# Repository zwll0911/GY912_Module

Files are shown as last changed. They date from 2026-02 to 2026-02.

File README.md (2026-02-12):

# 🚁 Industrial AHRS Navigation Module (V5.5)






> **High-Precision Navigation Core for Competition Robotics**

The **Industrial AHRS Navigation Module** is a robust sensor fusion engine built on the **ESP32-S3**. It delivers stable 6-axis orientation (Yaw, Pitch, Roll) via **1 Mbps CAN Bus** and offers **Dual-Mode Telemetry** (USB Serial + Wireless UDP) for real-time monitoring.

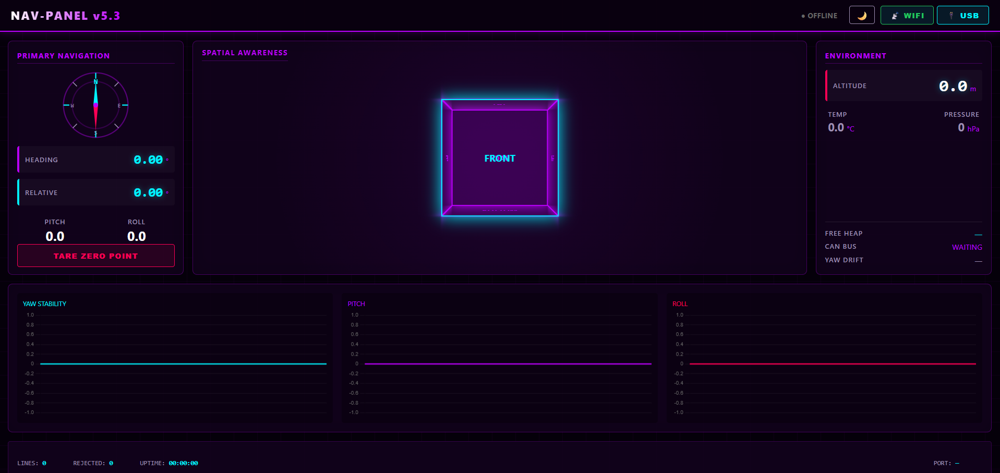
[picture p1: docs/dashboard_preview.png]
Dashboard Preview


---

## 📑 Table of Contents

- [Key Features](#-key-features)
- [System Architecture Overview](#-system-architecture-overview)
- [Sensor Fusion Pipeline (ICM-20948 DMP)](#-sensor-fusion-pipeline-icm-20948-dmp)
- [System Status Indicators](#-system-status-indicators)
- [FreeRTOS Task Architecture](#freertos-task-architecture)
- [Hardware Specifications](#️-hardware-specifications)
- [Quick Start](#-quick-start)
- [Documentation](#-documentation)
- [Project Structure](#-project-structure)

---

## 🚀 Key Features

| Feature | Detail |
| :--- | :--- |
| **DMP Sensor Fusion** | 6-axis fusion offloaded to ICM-20948 DMP using `GAME_ROTATION_VECTOR` at **225Hz** |
| **Wireless UDP** | Low-latency (~20ms) data streaming over WiFi (Broadcast to `192.168.4.255:4210`) |
| **Dual-Mode Dashboard** | Connect via USB (Web Serial) or Wireless (UDP Relay) for real-time visualization |
| **Power Optimized** | Efficient UDP broadcast, WiFi power save enabled, and smart task scheduling |
| **High-Speed CAN** | ESP32-S3 TWAI driver at **1 Mbps** for Robomaster C620/C610 speed controllers |
| **Environment Sensing** | BMP388 via SPI — Altitude (m), Pressure (hPa), Temperature (°C) at 50Hz ODR |
| **Cyberpunk UI** | NAV PANEL v5.4 — Smoothed 3D cube, 30Hz live graphs, tare heading, health stats |

---

## 🧠 System Architecture Overview

```mermaid
flowchart LR
    subgraph Hardware
        IMU["ICM-20948<br/>(DMP)"]
        BARO["BMP388"]
        Bus((CAN Bus<br/>1 Mbps))
        WiFi((WiFi AP<br/>UDP Broadcast))
    end

    subgraph Core1 ["Core 1: taskSensor (P3, 200Hz)"]
        direction TB
        FIFO[Read DMP FIFO]
        Quat["Quaternion"]
        Euler["Euler Angles"]
        BMP[Read BMP388]
        CSV[Build CSV]
    end

    subgraph Core0 ["Core 0"]
        direction TB
        CAN_Task["taskCAN (P2, 50Hz)"]
        LED_Task["taskLED (P1, 10Hz)"]
        Pool_Task["loop() (P1, Idle)"]
    end

    Mutex{{"🔒 Mutex"}}

    IMU -->|SPI 3MHz| FIFO
    FIFO --> Quat --> Euler
    BARO -->|SPI| BMP
    Euler & BMP --> CSV
    Euler --> Mutex
    Mutex --> CAN_Task
    CAN_Task -->|"ID:0x101"| Bus
    CSV -.->|Wireless| WiFi
```

---

## 🌀 Sensor Fusion Pipeline (ICM-20948 DMP)

The module offloads complex sensor fusion math to the ICM-20948's **Digital Motion Processor (DMP)**. This frees up the ESP32-S3 for CAN communication and logic.

1.  **Raw Data**: Accel + Gyro sampled internally at 1125Hz.
2.  **DMP Fusion**: 6-axis Game Rotation Vector algorithm runs on DMP.
3.  **FIFO Read**: ESP32 `taskSensor` reads Quaternion (q0, q1, q2, q3) at 225Hz.
4.  **Euler Conversion**: Quaternion converted to Yaw (-180 to +180), Pitch, Roll.
5.  **Output**: Data written to shared mutex variables and Serial/UDP stream.

---

## 💡 System Status Indicators

The module uses dual WS2812B RGB LEDs to communicate system state.

| LED | Pin | Pattern | Meaning | Technical Detail |
| :--- | :--- | :--- | :--- | :--- |
| **Device Status** | **1** | **Solid Green** | Normal Operation | System running, sensor fusion active |
| **Device Status** | **1** | **Breathing Blue** | WiFi / OTA Active | UDP streaming or OTA update pending |
| **Heartbeat** | **48** | **Purple Blink** (0.5Hz) | CPU Alive | Toggles every 1.5s (10Hz loop) |
| **Error** | **48** | **Solid Red** | DMP Init Failure | Sensor initialization failed. Check wiring. |

### FreeRTOS Task Architecture

The ESP32-S3 dual-core processor runs three dedicated FreeRTOS tasks plus the Arduino `loop()`:

1.  **`taskSensor` (Core 1, P3, 200Hz)**: Reads DMP FIFO, reads BMP388, updates orientation.
2.  **`taskCAN` (Core 0, P2, 50Hz)**: Handles CAN transmission and reception.
3.  **`taskLED` (Core 0, P1, 10Hz)**: Updates status LEDs.
4.  **`loop()` (Core 1, P1)**: Handles OTA updates and low-power sleep when idle.

---

## 🛠️ Hardware Specifications

| Component | Specification |
| :--- | :--- |
| **MCU** | ESP32-S3FH4R2 (Dual Core 240MHz, 4MB Flash, 2MB PSRAM) |
| **IMU** | TDK InvenSense ICM-20948 (9-Axis MEMS) |
| **Barometer** | Bosch BMP388 (Precision Altimeter) |
| **CAN Transceiver** | SN65HVD230 (3.3V Logic) |
| **Power Input** | 5V via USB-C or VIN Pin |
| **Logic Level** | 3.3V |

---

## ⚡ Quick Start

### 1. Hardware Setup (PCB v1.1)
Ensure the module is powered via 5V. The LEDs should light up:
- **Pin 1**: Solid Green (Normal) or Breathing Blue (WiFi).
- **Pin 48**: Blinking Purple (Heartbeat).

### 2. Flash Firmware
Use **PlatformIO** (recommended) or Arduino IDE.
- **PlatformIO**: Open project folder → Click `Upload`.
- **Arduino**: Open `firmware/esp32s3/esp32s3.ino` → Select "ESP32S3 Dev Module" → Upload.

### 3. Calibration
Place the module on a flat, stationary surface for 3 seconds after power-up. The DMP auto-calibrates gyro bias.

### 4. Connect CAN
Hook up `CAN H` and `CAN L` to your Robomaster bus network (**1 Mbps**).

### 5. Launch Dashboard (Dual Mode)
- **Wired:** Open `firmware/index.html` → Click **🔌 USB** → Select Port.
- **Wireless:** Connect to `NAV_MODULE_OTA` WiFi → Run `python firmware/udp_relay.py` → Click **📡 WIFI**.

---

## 📚 Documentation

| Document | Description |
| :--- | :--- |
| 📖 [Hardware & Pinout](docs/HARDWARE.md) | Wiring diagrams, pin maps, Mermaid connection diagram |
| 📡 [CAN Protocol](docs/CAN_PROTOCOL.md) | Message ID 0x101, byte-level packing, decoding math |
| 🏗️ [System Architecture](docs/ARCHITECTURE.md) | FreeRTOS tasks, DMP pipeline, quaternion math, data flow |
| 🖥️ [Web Dashboard](docs/WEB_DASHBOARD.md) | NAV PANEL v5.3 — Dual-mode connect, 3D cube, smoothing |
| 🔩 [PCB Design](docs/PCB_DESIGN.md) | Circuit block diagram and component BOM |
| 📋 [Changelog](CHANGELOG.md) | Full version history (v1.0 → v5.3) |

---

## 📂 Project Structure

```text
.
├── firmware/
│   ├── esp32s3/
│   │   └── esp32s3.ino       # Main firmware (FreeRTOS, DMP, CAN, LED)
│   ├── index.html            # NAV PANEL v5.3 (Web Serial + WebSocket)
│   ├── udp_relay.py          # Python UDP-to-WebSocket Relay
│   ├── chart.js              # Chart.js (bundled for offline use)
│   └── README.md             # Firmware-specific documentation
├── docs/
│   ├── ARCHITECTURE.md       # System architecture & math
│   ├── CAN_PROTOCOL.md       # CAN protocol specification
│   ├── HARDWARE.md           # Pinout & wiring guide
│   ├── WEB_DASHBOARD.md      # Dashboard user guide
│   ├── PCB_DESIGN.md         # PCB design documentation
│   └── dashboard_preview.png # Dashboard screenshot
├── v1/                       # KiCad PCB design files
├── .github/                  # CI workflow
├── LICENSE                   # MIT License
└── README.md                 # This file
```

---

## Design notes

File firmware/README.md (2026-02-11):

# 🔧 Firmware

This directory contains the ESP32-S3 firmware and ground control station files for the **Industrial AHRS Navigation Module (V5.1)**.

## 📁 Contents

| File/Folder | Description | Size |
| :--- | :--- | :--- |
| `esp32s3/esp32s3.ino` | Main firmware (FreeRTOS, DMP, CAN, LED) | ~6.7 KB |
| `index.html` | NAV PANEL v5.1 (Web Serial Dashboard) | ~16.4 KB |
| `chart.js` | Chart.js library (bundled for offline use) | ~208 KB |

## 🚀 Flashing the Firmware

### Prerequisites
- [PlatformIO](https://platformio.org/) (VSCode extension recommended)
- USB-C cable

### Required Libraries
| Library | Purpose |
| :--- | :--- |
| `SparkFun ICM-20948` | DMP sensor fusion driver |
| `Adafruit BMP3XX` | BMP388 barometer driver |
| `Adafruit NeoPixel` | WS2812B RGB LED control |
| `Adafruit Unified Sensor` | Sensor abstraction layer |

### Steps
1. Open `firmware/esp32s3/` folder in VSCode with PlatformIO.
2. Connect ESP32-S3 SuperMini via USB-C.
3. Click **Upload** (→) in PlatformIO toolbar.

## ⚙️ Configuration

### Serial Baud Rate
The firmware outputs CSV telemetry at **115200 baud** over USB Serial:
```cpp
Serial.begin(115200);
```

### DMP Initialization
The ICM-20948 DMP is configured for maximum responsiveness:
```cpp
myICM.begin(PIN_CS_ACCEL, SPI, 3000000);                               // SPI @ 3 MHz
myICM.initializeDMP();                                                   // Load DMP firmware
myICM.enableDMPSensor(INV_ICM20948_SENSOR_GAME_ROTATION_VECTOR, true);  // 6-axis fusion
myICM.setDMPODRrate(DMP_ODR_Reg_Quat6, 0);                             // 225 Hz (max)
myICM.enableFIFO();                                                      // FIFO routing
myICM.enableDMP();                                                       // Start DMP
myICM.resetDMP();                                                        // Clear state
myICM.resetFIFO();                                                       // Flush buffer
```

### BMP388 Barometer
```cpp
bmp.begin_SPI(PIN_CS_BARO, &SPI);
bmp.setTemperatureOversampling(BMP3_OVERSAMPLING_8X);   // High accuracy temp
bmp.setPressureOversampling(BMP3_OVERSAMPLING_4X);      // Balanced pressure
bmp.setIIRFilterCoeff(BMP3_IIR_FILTER_COEFF_3);        // Noise filtering
bmp.setOutputDataRate(BMP3_ODR_50_HZ);                  // 50 Hz output
```

**Altitude reference**: ISA sea-level pressure of **1013.25 hPa**. Adjust for local conditions if needed:
```cpp
alt = bmp.readAltitude(1013.25);  // Change this value for your location
```

### Calibration
- **DMP Init**: Onboard LED turns **solid red** if DMP initialization fails (system halts).
- **Gyro Zeroing**: Keep the module **still during boot** — DMP startup calibration eliminates drift.
- **No magnetometer**: GAME_ROTATION_VECTOR uses only Accel + Gyro (no magnetic interference).

### CAN Bus (TWAI)
| Parameter | Value |
| :--- | :--- |
| Speed | **1 Mbps** (`TWAI_TIMING_CONFIG_1MBITS()`) |
| TX Pin | `GPIO 5` |
| RX Pin | `GPIO 6` |
| Mode | Normal |
| Filter | Accept All |
| Message ID | `0x101` (Euler angles, 6 bytes, big-endian) |

### Pin Map

| Pin | Function | Direction |
| :--- | :--- | :--- |
| 12 | SPI SCK | Output |
| 13 | SPI MISO | Input |
| 11 | SPI MOSI | Output |
| 10 | CS_IMU (ICM-20948) | Output |
| 9 | CS_BARO (BMP388) | Output |
| 5 | CAN_TX | Output |
| 6 | CAN_RX | Input |
| 1 | External RGB LED | Output |
| 48 | Onboard RGB LED | Output |

### Serial Output Format (CSV, 13 fields)
```
0.0, 0.0, 0.0, Pitch, Roll, Yaw, Yaw, 0.0, 0.0, 0.0, Temp(°C), Pressure(hPa), Altitude(m)
```

## 🖥️ Using the Dashboard
See the [Web Dashboard Guide](../docs/WEB_DASHBOARD.md) for complete instructions.

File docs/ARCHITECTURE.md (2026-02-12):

# 🏗️ System Architecture

[🔙 **Back to Main README**](../README.md)

This document explains the complete software architecture, sensor fusion mathematics, and data flow of the **Industrial AHRS Navigation Module (V5.1)**.

---

## ⚡ FreeRTOS Task Architecture

The ESP32-S3 dual-core processor runs three dedicated FreeRTOS tasks plus the Arduino `loop()` function.

### Task Configuration

| Task | Function | Priority | Core | Stack | Rate | Delay |
| :--- | :--- | :--- | :--- | :--- | :--- | :--- |
| **taskSensor** | `taskSensor()` | 3 (Highest) | Core 1 | 4096 bytes | ~200Hz | `vTaskDelay(pdMS_TO_TICKS(5))` |
| **taskCAN** | `taskCAN()` | 2 (Mid) | Core 0 | 4096 bytes | 50Hz | `vTaskDelay(pdMS_TO_TICKS(20))` |
| **taskLED** | `taskLED()` | 1 (Lowest) | Core 0 | 2048 bytes | 10Hz | `vTaskDelay(pdMS_TO_TICKS(100))` |
| **loop()** | `loop()` | 1 (Lowest) | Core 1 | Default | Idle | `vTaskDelay(50)` / `(100)` |

### Task Creation Code
```cpp
xTaskCreatePinnedToCore(taskSensor, "IMU", 4096, NULL, 3, NULL, 1);  // Core 1
xTaskCreatePinnedToCore(taskCAN,    "CAN", 4096, NULL, 2, NULL, 0);  // Core 0
xTaskCreatePinnedToCore(taskLED,    "LED", 2048, NULL, 1, NULL, 0);  // Core 0
```

> [!TIP]
> **Why is `taskSensor` pinned to Core 1?**
> The ESP32-S3 TWAI (CAN) driver generates interrupts on Core 0 by default. Pinning the time-critical DMP FIFO reads to Core 1 prevents CAN bus interrupts from causing timing jitter in the sensor fusion loop.

## 🌈 LED Behaviour (taskLED)

### Pin 1 — External Status
- **Solid Green**: Normal Operation (Sensor Fusion Active)
- **Breathing Blue**: WiFi / OTA Active (UDP Streaming)

```cpp
if (otaInitialized) {
    // Breathing Blue logic
    breathVal += breathDir;
    if (breathVal >= 200 || breathVal <= 10) breathDir = -breathDir;
    extLED.setPixelColor(0, extLED.Color(0, 0, (uint8_t)breathVal));
} else {
    // Solid Green
    extLED.setPixelColor(0, extLED.Color(0, 80, 0));
}
```

### Pin 48 — Onboard Purple Heartbeat
```cpp
uint32_t purple = obLED.Color(60, 0, 150);
blinkTimer++;
if (blinkTimer >= 15) {  // Toggle every 15 × 100ms = 1.5s
    blinkState = !blinkState;
    obLED.setPixelColor(0, blinkState ? purple : off);
    blinkTimer = 0;
}
```

### Thread Safety — Mutex

The shared orientation data (`robotYaw`, `robotPitch`, `robotRoll`) is protected by a FreeRTOS mutex:

```cpp
SemaphoreHandle_t dataMutex = xSemaphoreCreateMutex();

// Writer (taskSensor):
if (xSemaphoreTake(dataMutex, portMAX_DELAY)) {
    robotYaw   = calculated_yaw;
    robotPitch = calculated_pitch;
    robotRoll  = calculated_roll;
    // ... serial output also inside mutex ...
    xSemaphoreGive(dataMutex);
}

// Reader (taskCAN):
if (xSemaphoreTake(dataMutex, portMAX_DELAY)) {
    int16_t y = (int16_t)(robotYaw * 100);
    int16_t p = (int16_t)(robotPitch * 100);
    int16_t r = (int16_t)(robotRoll * 100);
    xSemaphoreGive(dataMutex);
    // ... pack and transmit outside mutex ...
}
```

> [!NOTE]
> Both tasks use `portMAX_DELAY` (infinite blocking). This guarantees data consistency but means each task may briefly stall waiting for the other. Since sensor runs at 200Hz and CAN at 50Hz, contention is minimal.

---

## 🧠 DMP Sensor Fusion (ICM-20948)

### DMP Configuration

The ICM-20948's on-chip Digital Motion Processor handles the accelerometer + gyroscope fusion internally, outputting a quaternion.

| Parameter | Value | API Call |
| :--- | :--- | :--- |
| Sensor Mode | Game Rotation Vector (6-axis, no mag) | `enableDMPSensor(INV_ICM20948_SENSOR_GAME_ROTATION_VECTOR, true)` |
| Output Data Rate | 225 Hz (maximum) | `setDMPODRrate(DMP_ODR_Reg_Quat6, 0)` — divisor 0 = max rate |
| SPI Clock Speed | 3 MHz | `myICM.begin(PIN_CS_ACCEL, SPI, 3000000)` |
| Data Interface | FIFO Buffer | `enableFIFO()` + `enableDMP()` |

### DMP Initialization Sequence
```
1. myICM.begin()          → SPI connection at 3 MHz
2. myICM.initializeDMP()  → Load DMP firmware to ICM-20948
3. enableDMPSensor()      → Enable GAME_ROTATION_VECTOR
4. setDMPODRrate()        → Set output rate to 225Hz
5. enableFIFO()           → Route DMP output through FIFO
6. enableDMP()            → Start the DMP
7. resetDMP()             → Clear DMP state
8. resetFIFO()            → Flush FIFO buffer
```

If `initializeDMP()` fails, the onboard LED turns **solid red** and the system halts (`while(1)`).

### Quaternion Normalization

The DMP outputs raw 30-bit fixed-point quaternion components (Q1, Q2, Q3). The scalar component Q0 is not transmitted and must be recovered from the unit quaternion constraint:

```
q1 = raw_Q1 / 2³⁰           (2³⁰ = 1,073,741,824)
q2 = raw_Q2 / 2³⁰
q3 = raw_Q3 / 2³⁰
q0 = √(1 − q1² − q2² − q3²)  ← unit quaternion: |q| = 1
```

```cpp
// From esp32s3.ino, lines 109-112:
double q1 = ((double)data.Quat6.Data.Q1) / 1073741824.0;
double q2 = ((double)data.Quat6.Data.Q2) / 1073741824.0;
double q3 = ((double)data.Quat6.Data.Q3) / 1073741824.0;
double q0 = sqrt(1.0 - ((q1 * q1) + (q2 * q2) + (q3 * q3)));
```

### Quaternion → Euler Angle Conversion

The quaternion is converted to aerospace-convention Euler angles (ZYX intrinsic rotation order):

| Angle | Formula | Range |
| :--- | :--- | :--- |
| **Roll (φ)** | `atan2(2(q0·q1 + q2·q3), 1 − 2(q1² + q2²)) × 180/π` | ±180° |
| **Pitch (θ)** | `asin(2(q0·q2 − q3·q1)) × 180/π` | ±90° |
| **Yaw (ψ)** | `atan2(2(q0·q3 + q1·q2), 1 − 2(q2² + q3²)) × 180/π` | ±180° |

```cpp
// From esp32s3.ino, lines 115-117:
robotRoll  = atan2(2.0*(q0*q1 + q2*q3), 1.0 - 2.0*(q1*q1 + q2*q2)) * 180.0/PI;
robotPitch = asin(2.0*(q0*q2 - q3*q1)) * 180.0/PI;
robotYaw   = atan2(2.0*(q0*q3 + q1*q2), 1.0 - 2.0*(q2*q2 + q3*q3)) * 180.0/PI;
```

> [!IMPORTANT]
> **Gimbal Lock Warning**: The `asin()` function in the Pitch calculation will produce unstable results when Pitch approaches ±90°. This is a known limitation of Euler angle representations. For competition robotics operating on relatively flat surfaces, this is acceptable.

---

## 🌡️ BMP388 Barometer

### Configuration

| Parameter | Setting | API Call |
| :--- | :--- | :--- |
| Interface | SPI | `bmp.begin_SPI(PIN_CS_BARO, &SPI)` |
| Temp Oversampling | 8× | `setTemperatureOversampling(BMP3_OVERSAMPLING_8X)` |
| Pressure Oversampling | 4× | `setPressureOversampling(BMP3_OVERSAMPLING_4X)` |
| IIR Filter | Coefficient 3 | `setIIRFilterCoeff(BMP3_IIR_FILTER_COEFF_3)` |
| Output Data Rate | 50 Hz | `setOutputDataRate(BMP3_ODR_50_HZ)` |

### Calculations

```
Temperature (°C) = bmp.temperature                  (direct reading)
Pressure (hPa)   = bmp.pressure / 100.0              (BMP388 outputs Pa → convert to hPa)
Altitude (m)     = bmp.readAltitude(1013.25)          (barometric formula, ISA sea-level ref)
```

The altitude calculation uses the **International Standard Atmosphere (ISA)** barometric formula internally:

```
altitude = 44330.0 × (1.0 − (P / P₀)^0.1903)

Where:
  P  = measured pressure (hPa)
  P₀ = sea-level reference pressure = 1013.25 hPa
```

---

## 🔄 System Data Flow

```mermaid
flowchart TD
    subgraph BOOT ["Setup (runs once)"]
        direction LR
        SPI_Init["SPI.begin()"] --> ICM_Init["DMP Init<br/>225Hz Quat6"]
        ICM_Init --> BMP_Init["BMP388 Init<br/>50Hz, 8x/4x OS"]
        BMP_Init --> CAN_Init["TWAI Init<br/>1 Mbps"]
        CAN_Init --> Tasks["Create 3 Tasks"]
    end

    subgraph RUNTIME ["Runtime (3 parallel tasks)"]
        subgraph Core1 ["Core 1: taskSensor (P3, 5ms loop)"]
            direction TB
            FIFO["readDMPdataFromFIFO()"]
            QNorm["Normalize Quaternion<br/>÷ 2³⁰, recover q0"]
            EulerCalc["Euler Conversion<br/>atan2, asin"]
            BaroRead["bmp.performReading()"]
            SerialOut["Serial CSV<br/>13 fields @ 115200"]
        end

        subgraph Core0_CAN ["Core 0: taskCAN (P2, 20ms loop)"]
            direction TB
            MutexRead["Mutex Read<br/>Yaw, Pitch, Roll"]
            Scale["Scale × 100<br/>→ int16_t"]
            Pack["Big-Endian Pack<br/>6 bytes"]
            Transmit["twai_transmit()<br/>ID: 0x101"]
        end

        subgraph Core0_LED ["Core 0: taskLED (P1, 20ms loop)"]
            direction TB
            Rainbow["Pin 1: ColorHSV<br/>hue += 250"]
            Blink["Pin 48: Toggle<br/>every 15 loops"]
        end
    end

    FIFO --> QNorm --> EulerCalc --> BaroRead --> SerialOut
    EulerCalc -.->|"🔒 Mutex"| MutexRead
    MutexRead --> Scale --> Pack --> Transmit

    BOOT --> RUNTIME
```

### Serial CSV Output Format (13 Fields)

The sensor task outputs one CSV line per DMP reading at 115200 baud:

```
Index:   [0]  [1]  [2]   [3]     [4]    [5]   [6]   [7]  [8]  [9]   [10]   [11]      [12]
Field:   0.0, 0.0, 0.0, Pitch,  Roll,  Yaw,  Yaw,  0.0, 0.0, 0.0, Temp, Pressure, Altitude
Unit:     —    —    —    deg     deg    deg    deg    —    —    —    °C     hPa        m
```

> [!NOTE]
> Fields [0-2] and [7-9] are reserved (sent as `0.0` for legacy compatibility). Field [6] is a duplicate of field [5] (Yaw).

---

## 🔌 CAN Bus (TWAI)

### Configuration
```cpp
twai_general_config_t g_config = TWAI_GENERAL_CONFIG_DEFAULT(
    (gpio_num_t)PIN_CAN_TX,    // GPIO 5
    (gpio_num_t)PIN_CAN_RX,    // GPIO 6
    TWAI_MODE_NORMAL
);
twai_timing_config_t t_config = TWAI_TIMING_CONFIG_1MBITS();
twai_filter_config_t f_config = TWAI_FILTER_CONFIG_ACCEPT_ALL();
```

### Data Packing
See [CAN Protocol Specification](CAN_PROTOCOL.md) for complete byte-level details.

---

## 🌈 LED Behaviour (taskLED)

### Pin 1 — External Rainbow Cycle
```cpp
extLED.setPixelColor(0, extLED.ColorHSV(rainbowHue));  // HSV color wheel
rainbowHue += 250;  // Full cycle = 65536 / 250 = ~262 loops = ~5.2 seconds
```

### Pin 48 — Onboard Purple Heartbeat
```cpp
uint32_t purple = obLED.Color(60, 0, 150);  // Neon Purple (R:60 G:0 B:150)
blinkTimer++;
if (blinkTimer >= 15) {  // Toggle every 15 × 20ms = 300ms → 0.6s period ≈ 1.67Hz
    blinkState = !blinkState;
    obLED.setPixelColor(0, blinkState ? purple : off);
    blinkTimer = 0;
}
```

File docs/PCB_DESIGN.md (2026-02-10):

# 🔩 PCB Design (V1)

[🔙 **Back to Main README**](../README.md)

This document describes the custom PCB design for the **Industrial AHRS Navigation Module**.

> [!NOTE]
> The raw design files are located in the `v1/` directory and can be opened with **KiCad 8+**.

---

## 📐 Board Overview

| Parameter | Value |
| :--- | :--- |
| **PCB Layers** | 2-Layer |
| **Logic Level** | 3.3V |
| **MCU** | ESP32-S3 SuperMini (Module) |
| **Design Tool** | KiCad 8 |

---

## 🧩 Component List (BOM)

| Ref | Component | Package | Function |
| :--- | :--- | :--- | :--- |
| U1 | **ESP32-S3 SuperMini** | Module | Main Controller |
| U2 | **ICM-20948** | LGA-24 | 9-DOF IMU (Accel/Gyro/Mag) |
| U3 | **BMP388** | LGA-10 | Precision Barometer |
| U4 | **SN65HVD230** | SOIC-8 | CAN Bus Transceiver |
| D1 | **WS2812B** | 5050 | Onboard RGB LED |
| D2 | **WS2812B** | 5050 | External RGB LED |
| J1 | **USB-C** | - | Programming & Power |
| J2 | **CAN Header** | 2-Pin | CAN H / CAN L |

---

## 🔌 Circuit Block Diagram

```mermaid
graph TB
    subgraph Power
        USB["USB-C 5V"] --> REG["3.3V Regulator"]
    end

    subgraph MCU
        ESP["ESP32-S3 SuperMini"]
    end

    subgraph SPI Bus
        IMU["ICM-20948"]
        BARO["BMP388"]
    end

    subgraph CAN
        XCVR["SN65HVD230"]
        BUS(("CAN Bus<br/>H / L"))
    end

    subgraph LEDs
        LED1["WS2812B (Onboard)"]
        LED2["WS2812B (External)"]
    end

    REG -->|3.3V| ESP
    REG -->|3.3V| IMU
    REG -->|3.3V| BARO
    REG -->|3.3V| XCVR

    ESP -->|SPI + CS| IMU
    ESP -->|SPI + CS| BARO
    ESP -->|TX/RX| XCVR
    XCVR -->|H/L| BUS
    ESP -->|Data Pin 48| LED1
    ESP -->|Data Pin 1| LED2
```

---

## 📁 Design Files

| File | Description |
| :--- | :--- |
| `v1/v1.kicad_sch` | Schematic |
| `v1/v1.kicad_pcb` | PCB Layout |
| `v1/v1.kicad_pro` | Project File |

> [!TIP]
> To view these files, install [KiCad](https://www.kicad.org/) (free, open-source) and open `v1/v1.kicad_pro`.

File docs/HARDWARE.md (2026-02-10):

# 📟 Hardware Wiring & Pinout

[🔙 **Back to Main README**](../README.md)

This document details the hardware connections for the **Industrial AHRS Navigation Module (V3.0)**.

---

## 📌 Pinout Configuration

The module uses the **ESP32-S3 SuperMini**. Below is the complete pin mapping.

| ESP32-S3 Pin | Function | Description | Type |
| :--- | :--- | :--- | :--- |
| **12** | `SCK` | SPI Clock | Output |
| **13** | `MISO` | SPI Master In Slave Out | Input |
| **11** | `MOSI` | SPI Master Out Slave In | Output |
| **10** | `CS_IMU` | Chip Select (ICM-20948) | Output |
| **9** | `CS_BARO` | Chip Select (BMP388) | Output |
| **5** | `CAN_TX` | CAN Bus Transmit | Output |
| **6** | `CAN_RX` | CAN Bus Receive | Input |
| **48** | `LED_Builtin` | Onboard RGB LED | Output |
| **1** | `LED_Ext` | External RGB LED Data Line | Output |

---

## 🔌 Connection Diagram

The following diagram illustrates the signal flow between the components.

```mermaid
graph TD
    subgraph ESP32-S3 SuperMini
        SCK["Pin 12 (SCK)"]
        MISO["Pin 13 (MISO)"]
        MOSI["Pin 11 (MOSI)"]
        CS_IMU["Pin 10 (CS_IMU)"]
        CS_BARO["Pin 9 (CS_BARO)"]
        TX["Pin 5 (TX)"]
        RX["Pin 6 (RX)"]
        LED["Pin 1 (LED Data)"]
    end

    subgraph Sensors
        ICM["ICM-20948 IMU"]
        BMP["BMP388 Barometer"]
    end

    subgraph Peripherals
        CAN["CAN Transceiver"]
        RGB["External RGB LED"]
    end

    SCK --> ICM
    SCK --> BMP
    ICM --> MISO
    BMP --> MISO
    MOSI --> ICM
    MOSI --> BMP
    CS_IMU --> ICM
    CS_BARO --> BMP
    TX --> CAN
    CAN --> RX
    LED --> RGB
```

---

> [!WARNING]
> **⚡ Power Voltage Warning**
>
> The ESP32-S3 operates at **3.3V logic levels**.
> *   **Do not connect 5V signals** directly to any GPIO pins, as this may damage the MCU.
> *   Ensure your CAN transceiver and sensors are **3.3V compatible** or use appropriate logic level shifters.

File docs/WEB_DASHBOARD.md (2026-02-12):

# 🖥️ Web Dashboard — NAV PANEL v5.5

[🔙 **Back to Main README**](../README.md)

The **NAV PANEL** is a browser-based ground control station for real-time telemetry monitoring and 3D orientation visualization. It supports **Dual-Mode Connectivity**:
1.  **USB Serial**: Direct connection via Web Serial API (Chrome/Edge only).
2.  **Wireless UDP**: Low-latency streaming over WiFi via a local Python relay.

Features a **Cyberpunk Neon Purple & Cyan** theme, now with **smoothed animations** (3D cube, compass) and **30Hz charts**.

Dashboard Preview

---

## ⚡ Quick Start

### Option A: USB Serial (Wired)
1.  Connect ESP32-S3 via USB.
2.  Click **🔌 USB**.
3.  Select COM port.

### Option B: Wireless UDP (WiFi)
1.  Connect laptop to `NAV_MODULE_OTA` WiFi.
2.  Run the relay script: `python firmware/udp_relay.py`.
3.  Click **📡 WIFI** (connects to `ws://localhost:8765`).

---

## 🎨 Design System

### CSS Variables (Color Palette)
```css
:root {
    --primary-purple: #bd00ff;    /* Panel headers, borders, glow effects */
    --accent-cyan:    #00f3ff;    /* Data values, connect button, online status */
    --alert-pink:     #ff0055;    /* Tare button, roll graph, altitude accent */
    --bg-dark:        #05000a;    /* Background (near-black with purple tint) */
    --panel-bg:       rgba(18, 2, 28, 0.9);  /* Semi-transparent panel fill */
    --text-dim:       #9e8fb2;    /* Labels, secondary text */
}
```

### Layout
- **Grid**: `grid-template-columns: 300px 1fr 300px` / `grid-template-rows: 60% 40%`
- **Viewport**: `100vw × 100vh` with `overflow: hidden` (no scrolling)
- **Background**: 40×40px purple grid lines for cyberpunk aesthetic
- **Typography**: Segoe UI / Verdana (system), Consolas (monospace values)

---

## 📊 Panel Reference

### Panel 1 — Primary Navigation (Left Column)

| Element | ID | Data Source | Format |
| :--- | :--- | :--- | :--- |
| **HEADING** | `#v_y` | CSV field [5] (Yaw) | `y.toFixed(2)` → `"145.30"` |
| **RELATIVE** | `#v_yr` | Yaw − Tare offset | `(y - tareVal).toFixed(2)` |
| **PITCH** | `#v_p` | CSV field [3] (Pitch) | `p.toFixed(1)` → `"2.5"` |
| **ROLL** | `#v_r` | CSV field [4] (Roll) | `r.toFixed(1)` → `"-1.1"` |
| **TARE ZERO POINT** | `#btnTare` | Captures current Yaw | `tareVal = parseFloat(v_y.innerText)` |

#### Tare Calculation
```javascript
// On button press: capture current Yaw as the zero reference
document.getElementById('btnTare').onclick = () => {
    tareVal = parseFloat(document.getElementById('v_y').innerText);
};

// On each update: subtract tare from raw yaw
relative_heading = yaw - tareVal;
```

This allows the driver to **instantly reset the front-facing heading to 0°** from any arbitrary position.

### Panel 2 — Spatial Awareness (Center)

A **CSS 3D cube** (180×180px) mirrors the robot's physical orientation in real-time.

#### 3D Transform Mapping
```javascript
// From index.html, line 449:
cube.style.transform = `rotateX(${-p}deg) rotateY(${y}deg) rotateZ(${-r}deg)`;
```

| CSS Transform | Sensor Axis | Sign | Reason |
| :--- | :--- | :--- | :--- |
| `rotateX()` | Pitch | **Inverted** (`-p`) | CSS rotateX positive = tilt forward, sensor positive = nose up |
| `rotateY()` | Yaw | Normal (`y`) | Both conventions agree on clockwise = positive |
| `rotateZ()` | Roll | **Inverted** (`-r`) | CSS rotateZ positive = counter-clockwise, sensor positive = right wing down |

#### CSS 3D Configuration
```css
#sim-container { perspective: 900px; }
#cube {
    width: 180px; height: 180px;
    transform-style: preserve-3d;
    transition: transform 80ms ease-out;  /* Smooths rotation between 50Hz updates */
    will-change: transform;               /* GPU acceleration hint */
}
.face { backface-visibility: visible; }
.front { transform: translateZ(90px); }     /* Cyan highlight */
.back  { transform: rotateY(180deg) translateZ(90px); }
.right { transform: rotateY(90deg) translateZ(90px); }
.left  { transform: rotateY(-90deg) translateZ(90px); }
.top   { transform: rotateX(90deg) translateZ(90px); }
.bottom{ transform: rotateX(-90deg) translateZ(90px); }
```

### Panel 3 — Environment (Right Column)

| Element | ID | Data Source | Format | Unit |
| :--- | :--- | :--- | :--- | :--- |
| **ALTITUDE** | `#v_alt` | CSV field [12] | `alt.toFixed(1)` | m |
| **TEMP** | `#v_temp` | CSV field [10] | `temp.toFixed(1)` | °C |
| **PRESSURE** | `#v_press` | CSV field [11] | `d[11].toFixed(0)` | hPa |

### Panel 3 (cont.) — System Health

| Indicator | Data Source | Details |
| :--- | :--- | :--- |
| **FREE HEAP** | CSV field [13] | ESP32 free memory in KB (e.g., `210 KB`) |
| **CAN BUS** | CSV field [14] | Status: `OK (1 MBPS)` or `ERR:<count>` |
| **YAW DRIFT** | CSV field [15] | Gyro drift rate in °/s (Color-coded: Cyan < 0.05) |

### Panel 4 — Stability Graphs (Bottom Row, spans 3 columns)

Three separate **Chart.js** line graphs track orientation stability:

| Graph | Canvas ID | Color | Data Source | Line |
| :--- | :--- | :--- | :--- | :--- |
| **YAW STABILITY** | `#chartYaw` | `#00f3ff` (Cyan) | `yaw - tareVal` | 2px, tension 0.3 |
| **PITCH** | `#chartPitch` | `#bd00ff` (Purple) | Pitch (raw) | 2px, tension 0.3 |
| **ROLL** | `#chartRoll` | `#ff0055` (Pink) | Roll (raw) | 2px, tension 0.3 |

#### Chart Configuration
```javascript
const commonOptions = {
    responsive: true,
    maintainAspectRatio: false,
    plugins: { legend: { display: false } },
    scales: {
        x: { display: false },              // No X-axis labels
        y: { grid: { color: 'rgba(255,255,255,0.05)' },
             ticks: { color: '#666', font: { size: 9 } } }
    },
    animation: false,                        // Disabled for performance
    elements: { point: { radius: 0 } }       // No data points (line only)
};
```

- **Window size**: 40 samples (rolling buffer)
- **Update method**: `push()` + `shift()` — FIFO

```javascript
function updateGraph(chart, val) {
    chart.data.datasets[0].data.push(val);   // Add new value
    chart.data.datasets[0].data.shift();     // Remove oldest
    chart.update();
}
```

---

## 🔌 Dual-Mode Connection (USB / UDP)

### Connection Flow

```mermaid
sequenceDiagram
    participant User
    participant Browser
    participant Relay as Python Relay
    participant ESP32 as ESP32-S3

    alt USB Mode (Wired)
        Browser->>ESP32: Web Serial API (115200 baud)
        ESP32->>Browser: Serial CSV Stream
    else UDP Mode (Wireless)
        ESP32->>Relay: UDP Broadcast (Port 4210)
        Relay->>Browser: WebSocket (ws://localhost:8765)
        Note over Relay: Zero-latency local forwarding
    end

    Browser->>Browser: Update DOM + 3D Cube (Smooth Transition)
    Browser->>Browser: Plot Charts (30Hz)
```

### Serial Data Parsing

```javascript
// From index.html, lines 433-455:
function update(line) {
    const d = line.split(',').map(Number);  // Parse CSV → number array
    if (d.length < 13) return;               // Reject incomplete lines

    // Extract fields by index:
    const p = d[3];      // Pitch (degrees)
    const r = d[4];      // Roll (degrees)
    const y = d[5];      // Yaw (degrees)
    const temp = d[10];  // Temperature (°C)
    const alt = d[12];   // Altitude (m)
    // d[11] = Pressure (hPa) — used inline

    // Update readouts
    v_y.innerText    = y.toFixed(2);              // Heading
    v_yr.innerText   = (y - tareVal).toFixed(2);  // Relative (tared)
    v_p.innerText    = p.toFixed(1);              // Pitch
    v_r.innerText    = r.toFixed(1);              // Roll
    v_temp.innerText = temp.toFixed(1);           // Temperature
    v_press.innerText= d[11].toFixed(0);          // Pressure
    v_alt.innerText  = alt.toFixed(1);            // Altitude

    // Update 3D Cube (pitch & roll inverted for CSS convention)
    cube.style.transform = `rotateX(${-p}deg) rotateY(${y}deg) rotateZ(${-r}deg)`;

    // Update Graphs
    updateGraph(chartYaw, y - tareVal);
    updateGraph(chartPitch, p);
    updateGraph(chartRoll, r);
}
```

### Line Buffering Logic
```javascript
async function readLoop() {
    let buffer = "";
    while (true) {
        const { value, done } = await reader.read();
        if (done) break;
        buffer += value;                      // Accumulate partial reads
        let lines = buffer.split('\n');       // Split by newline
        buffer = lines.pop();                 // Keep incomplete last line
        for (let line of lines)
            if (line.includes(',')) update(line);  // Process complete lines
    }
}
```

> [!TIP]
> The buffer pattern handles the case where a serial read returns a partial CSV line. Data is accumulated until a complete line (ending with `\n`) is available.

---

## 🔧 Serial Configuration

| Parameter | Value |
| :--- | :--- |
| **Baud Rate** | `115200` |
| **Data Format** | CSV (13 comma-separated values per line) |
| **Encoding** | UTF-8 (via `TextDecoderStream`) |

### Expected Input Format (from firmware)
```
Index:  [0]  [1]  [2]   [3]     [4]    [5]   [6]   [7]  [8]  [9]   [10]   [11]      [12]
Field:  0.0, 0.0, 0.0, Pitch,  Roll,  Yaw,  Yaw,  0.0, 0.0, 0.0, Temp, Pressure, Altitude
Unit:    —    —    —    deg     deg    deg    deg    —    —    —    °C     hPa        m
```

Fields [0-2] and [7-9] are reserved (sent as `0.0`). Field [6] duplicates field [5].

> [!TIP]
> **Offline Ready**: The `chart.js` library is bundled locally in the `firmware/` folder. This dashboard works **100% offline** — no internet connection required at competition venues.

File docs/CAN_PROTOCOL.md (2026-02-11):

# 📡 CAN Bus Protocol Specification

[🔙 **Back to Main README**](../README.md)

This document defines the complete CAN bus communication protocol for the **Industrial AHRS Navigation Module (V5.1)**, including byte-level packing, decoding mathematics, and implementation examples.

---

## 📋 Protocol Summary

| Parameter | Value |
| :--- | :--- |
| **Driver** | ESP32-S3 TWAI (Two-Wire Automotive Interface) |
| **Baud Rate** | 1 Mbps (`TWAI_TIMING_CONFIG_1MBITS()`) |
| **Mode** | Normal (`TWAI_MODE_NORMAL`) |
| **Filter** | Accept All (`TWAI_FILTER_CONFIG_ACCEPT_ALL()`) |
| **ID Format** | Standard 11-bit |
| **Byte Order** | Big Endian (MSB first) |
| **Transmit Rate** | 50 Hz (every 20ms) |
| **Transmit Timeout** | 10ms (`pdMS_TO_TICKS(10)`) |
| **Target Devices** | Robomaster C620/C610 speed controllers |

---

## 🆔 Message Definition

The module transmits a **single CAN frame** per cycle:

| CAN ID | Description | DLC | Byte 0 | Byte 1 | Byte 2 | Byte 3 | Byte 4 | Byte 5 |
| :--- | :--- | :--- | :--- | :--- | :--- | :--- | :--- | :--- |
| **0x101** | Orientation | **6** | Yaw Hi | Yaw Lo | Pitch Hi | Pitch Lo | Roll Hi | Roll Lo |

> [!NOTE]
> `data_length_code = 6`. Only 6 of the 8 available CAN data bytes are used. Bytes 6 and 7 are not transmitted.

---

## 🧮 Data Packing (Firmware Side)

### Step 1: Float → Fixed-Point Scaling

Each Euler angle (in degrees) is multiplied by 100 and cast to a signed 16-bit integer:

```cpp
int16_t y = (int16_t)(robotYaw   * 100);  // e.g., 145.30° → 14530
int16_t p = (int16_t)(robotPitch * 100);  // e.g.,   2.45° →   245
int16_t r = (int16_t)(robotRoll  * 100);  // e.g.,  -1.10° →  -110
```

| Property | Value |
| :--- | :--- |
| Data type | `int16_t` (signed 16-bit) |
| Range | -32,768 to +32,767 |
| Resolution | 0.01° per LSB |
| Max representable | ±327.67° |

### Step 2: Big-Endian Byte Packing

Each `int16_t` is split into two bytes, **MSB first**:

```cpp
// Yaw → bytes [0..1]
message.data[0] = (y >> 8) & 0xFF;   // High byte (MSB)
message.data[1] = y & 0xFF;          // Low byte (LSB)

// Pitch → bytes [2..3]
message.data[2] = (p >> 8) & 0xFF;
message.data[3] = p & 0xFF;

// Roll → bytes [4..5]
message.data[4] = (r >> 8) & 0xFF;
message.data[5] = r & 0xFF;
```

### Packing Example

For orientation `Yaw=145.30°, Pitch=2.45°, Roll=-1.10°`:

```
Yaw   → 14530   → 0x38C2 → data[0]=0x38, data[1]=0xC2
Pitch →   245   → 0x00F5 → data[2]=0x00, data[3]=0xF5
Roll  →  -110   → 0xFF92 → data[4]=0xFF, data[5]=0x92
                              (two's complement for negative)

CAN Frame: [0x38, 0xC2, 0x00, 0xF5, 0xFF, 0x92]
```

---

## 🔓 Data Decoding (Receiver Side)

### Step 1: Reconstruct `int16_t` from Big-Endian Bytes

```cpp
// C/C++ Receiver Example:
int16_t yaw_raw   = (int16_t)((data[0] << 8) | data[1]);
int16_t pitch_raw = (int16_t)((data[2] << 8) | data[3]);
int16_t roll_raw  = (int16_t)((data[4] << 8) | data[5]);
```

### Step 2: Convert to Degrees

```cpp
float yaw_deg   = yaw_raw   / 100.0f;   // 14530 → 145.30°
float pitch_deg = pitch_raw / 100.0f;    //   245 →   2.45°
float roll_deg  = roll_raw  / 100.0f;    //  -110 →  -1.10°
```

### Python Example
```python
import struct

def decode_orientation(data):
    """Decode 6-byte CAN payload to Euler angles."""
    yaw_raw   = struct.unpack('>h', bytes(data[0:2]))[0]  # '>h' = big-endian int16
    pitch_raw = struct.unpack('>h', bytes(data[2:4]))[0]
    roll_raw  = struct.unpack('>h', bytes(data[4:6]))[0]
    return {
        'yaw':   yaw_raw   / 100.0,
        'pitch': pitch_raw / 100.0,
        'roll':  roll_raw  / 100.0,
    }

# Example:
payload = [0x38, 0xC2, 0x00, 0xF5, 0xFF, 0x92]
result = decode_orientation(payload)
# → {'yaw': 145.30, 'pitch': 2.45, 'roll': -1.10}
```

---

## 💻 Decoded Data Example (JSON)

```json
{
  "can_id": "0x101",
  "dlc": 6,
  "raw_hex": "38 C2 00 F5 FF 92",
  "decoded": {
    "yaw_deg": 145.30,
    "pitch_deg": 2.45,
    "roll_deg": -1.10
  }
}
```

---

## ⏱️ Timing & Thread Safety

| Parameter | Value |
| :--- | :--- |
| **Source Task** | `taskCAN` (Priority 2, Core 0) |
| **Transmit Interval** | 20ms (50 Hz) |
| **Transmit Timeout** | 10ms — frame is dropped if bus is busy longer |
| **Data Source** | Mutex-protected read from `taskSensor` shared variables |
| **Mutex Policy** | `portMAX_DELAY` — blocks until data is available |

```mermaid
sequenceDiagram
    participant Sensor as taskSensor (Core 1)
    participant Mutex as 🔒 Mutex
    participant CAN as taskCAN (Core 0)
    participant Bus as CAN Bus

    loop Every 5ms
        Sensor->>Mutex: Take (write Yaw/Pitch/Roll)
        Sensor->>Mutex: Give
    end

    loop Every 20ms
        CAN->>Mutex: Take (read Yaw/Pitch/Roll)
        Mutex-->>CAN: float values
        CAN->>CAN: Scale ×100, cast int16_t
        CAN->>Mutex: Give
        CAN->>CAN: Big-endian pack (6 bytes)
        CAN->>Bus: twai_transmit(0x101)
    end
```

---

## 🔌 Hardware Configuration

| Pin | Function | Direction |
| :--- | :--- | :--- |
| **GPIO 5** | CAN TX | Output |
| **GPIO 6** | CAN RX | Input |

Transceiver: **SN65HVD230** (3.3V compatible, no level shifter needed).

> [!WARNING]
> The CAN bus requires proper **120Ω termination resistors** at each end of the bus. Without termination, signal reflections will cause communication errors at 1 Mbps.

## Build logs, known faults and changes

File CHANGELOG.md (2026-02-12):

# 📋 Changelog

All notable changes to the **Industrial AHRS Navigation Module** will be documented in this file.

---

## [5.5] — 2026-02-12

### 📚 Documentation & Branding
- **Updated LED Status**: Corrected documentation to reflect Solid Green (Normal) and Breathing Blue (WiFi) patterns.
- **Task Architecture**: Clarified that `loop()` is active (not deleted) and handles OTA/Sleep.
- **System Health**: Updated dashboard documentation to match dynamic fields (Heap, CAN Status, Drift).
- **Branding**: Removed "Robocon" references for a more general-purpose industrial focus.
- **Assets**: Updated `dashboard_preview.png` with latest UI.

## [5.4] — 2026-02-12

### 🚀 UDP Streaming & Power Optimization
- **UDP Broadcast**: Replaced TCP WebSocket with connectionless UDP broadcast on port 4210. Latency reduced from >2s to ~20ms.
- **Power Save**: Re-enabled WiFi modem sleep (DTIM 3) to reduce power consumption (UDP handles this well).
- **CPU Optimization**: Completely removed `AsyncWebServer` and `AsyncWebSocket` overhead. Reduced LED task to 10Hz. Optimized loop delay.

### 🖥️ Dashboard (Dual-Mode)
- **Wireless Relay**: Added `udp_relay.py` to bridge UDP packets to local WebSocket (`ws://localhost:8765`).
- **Smooth Animations**: Added CSS `ease-out` transitions to 3D cube and compass for fluid movement.
- **30Hz Charts**: Increased graph render rate from 15Hz to 30Hz.
- **Dual Connectivity**: Toggle between **🔌 USB** (Web Serial) and **📡 WIFI** (UDP Relay).

## [5.3] — 2026-02-12

### 🔧 Firmware Improvements
- **Yaw Drift Indicator**: Exponential moving average of yaw rate-of-change (°/s) with wraparound handling. Added as CSV field [15].
- **Bidirectional CAN**: Added `twai_receive()` handler for incoming commands on `0x200`:
  - `0x01` → Remote TARE (zero yaw offset).
  - `0x02` + 4-byte float → Set sea-level pressure (saved to NVS).
  - `0x03` → Heartbeat reply on `0x102` with heap KB.
- **OTA Firmware Updates**: WiFi AP mode (`NAV_MODULE_OTA`, password: `navmodule`) with ArduinoOTA. Toggle via serial commands `OTA_ON` / `OTA_OFF`. State persisted in NVS.
- **Configurable CAN**: TX message ID and transmit interval stored in NVS (defaults: `0x101`, 20ms/50Hz).
- **Altitude Smoothing**: 10-sample circular buffer moving average on BMP388 altitude readings.

### 🖥️ Dashboard Improvements
- **SVG Compass Rose**: Real-time rotating compass needle synchronized with yaw heading.
- **Theme Toggle**: Dark (cyberpunk) / Light (high-contrast) theme switch. Saved to `localStorage`. Chart grid colors update with theme.
- **Error Counters**: Status bar showing total lines received, rejected lines, and connection uptime timer.
- **Yaw Drift Display**: Live drift rate (°/s) with color-coded severity (cyan/yellow/red).
- **CSV Recorder**: Now includes drift rate field in exported CSV.

### 🧪 Tests
- **Added** `tests/test_can_packing.py`: 20+ pytest cases for CAN byte packing/unpacking including edge cases, round-trip, and full payload verification.

### 📁 Project Structure
- **Added** `tests/` directory.

---

## [5.2] — 2026-02-12

### 🔧 Firmware Improvements
- **Mutex Optimization**: Moved `Serial.print()` and `bmp.performReading()` outside the mutex lock, reducing CAN task blocking time.
- **CAN Bus Recovery**: Added `twai_get_status_info()` health check and automatic `twai_initiate_recovery()` on bus-off errors.
- **Task Watchdog**: Registered `taskSensor` with ESP32 Task Watchdog Timer (TWDT) for 5-second hang detection.
- **Live Health Telemetry**: Added free heap size and CAN TX error count as CSV fields [13] and [14] (total 15 fields).
- **NVS Settings**: Sea-level pressure reference stored in Non-Volatile Storage via `Preferences` library (default 1013.25 hPa).

### 🖥️ Dashboard Improvements
- **Offline Fix**: Switched Chart.js from CDN to local bundled copy — no internet required.
- **Disconnect Handling**: Dashboard now detects USB disconnection and shows `DISCONNECTED` status.
- **Reconnect Button**: CONNECT button re-appears as RECONNECT after disconnection (no page refresh needed).
- **CSV Flight Recorder**: Added REC/STOP button with pulsing animation — exports timestamped CSV file.
- **Live System Health**: Free Heap (KB) and CAN Bus status now update in real-time from firmware telemetry.

### 📁 Project Structure
- **Added**: `platformio.ini` for PlatformIO users (Arduino IDE remains primary).
- **Added**: `CHANGELOG.md` (this file).

---

## [5.1] — 2026-02-10

### 🔧 Firmware
- **DMP Sensor Fusion**: Offloaded 6-axis fusion to ICM-20948 DMP using `GAME_ROTATION_VECTOR` at 225Hz.
- **3-Task FreeRTOS**: Migrated to `taskSensor` (P3, Core 1), `taskCAN` (P2, Core 0), `taskLED` (P1, Core 0).
- **Thread Safety**: Added `xSemaphoreCreateMutex()` for shared Yaw/Pitch/Roll data.
- **CAN Bus (TWAI)**: Activated at 1 Mbps for Robomaster C620/C610.
- **BMP388 Integration**: Altitude, Pressure, Temperature via SPI at 50Hz.
- **Dual LED Status**: Rainbow cycle (Pin 1) + Purple heartbeat (Pin 48).

### 🖥️ Dashboard (NAV PANEL v5.1)
- **Cyberpunk Theme**: Neon Purple & Cyan palette for competition visibility.
- **Responsive Grid**: CSS Grid layout, 100vh, no scrolling.
- **3D Simulation**: Real-time CSS 3D cube mirroring robot orientation.
- **Multi-Graph System**: Three Chart.js graphs (Yaw, Pitch, Roll).
- **Tare Zero Point**: Instant relative heading reset.
- **Environment Panel**: Live Altitude, Temperature, Pressure display.

---

## [3.0] — 2026-02-08

### 🔧 Firmware
- Initial ESP32-S3 firmware with Madgwick sensor fusion at 100Hz.
- CAN Bus output at 500 kbps.
- Single RGB LED with state-based color patterns.

### 🖥️ Dashboard
- Initial web dashboard with accelerometer, gyroscope, magnetometer panels.
- 3D orientation cube.
- Simulation mode for hardware-free testing.
- Flight recorder with CSV export.

---

## [1.0] — 2025-11-01

### Initial Release
- KiCad PCB design (v1).
- Basic sensor reading and serial output.

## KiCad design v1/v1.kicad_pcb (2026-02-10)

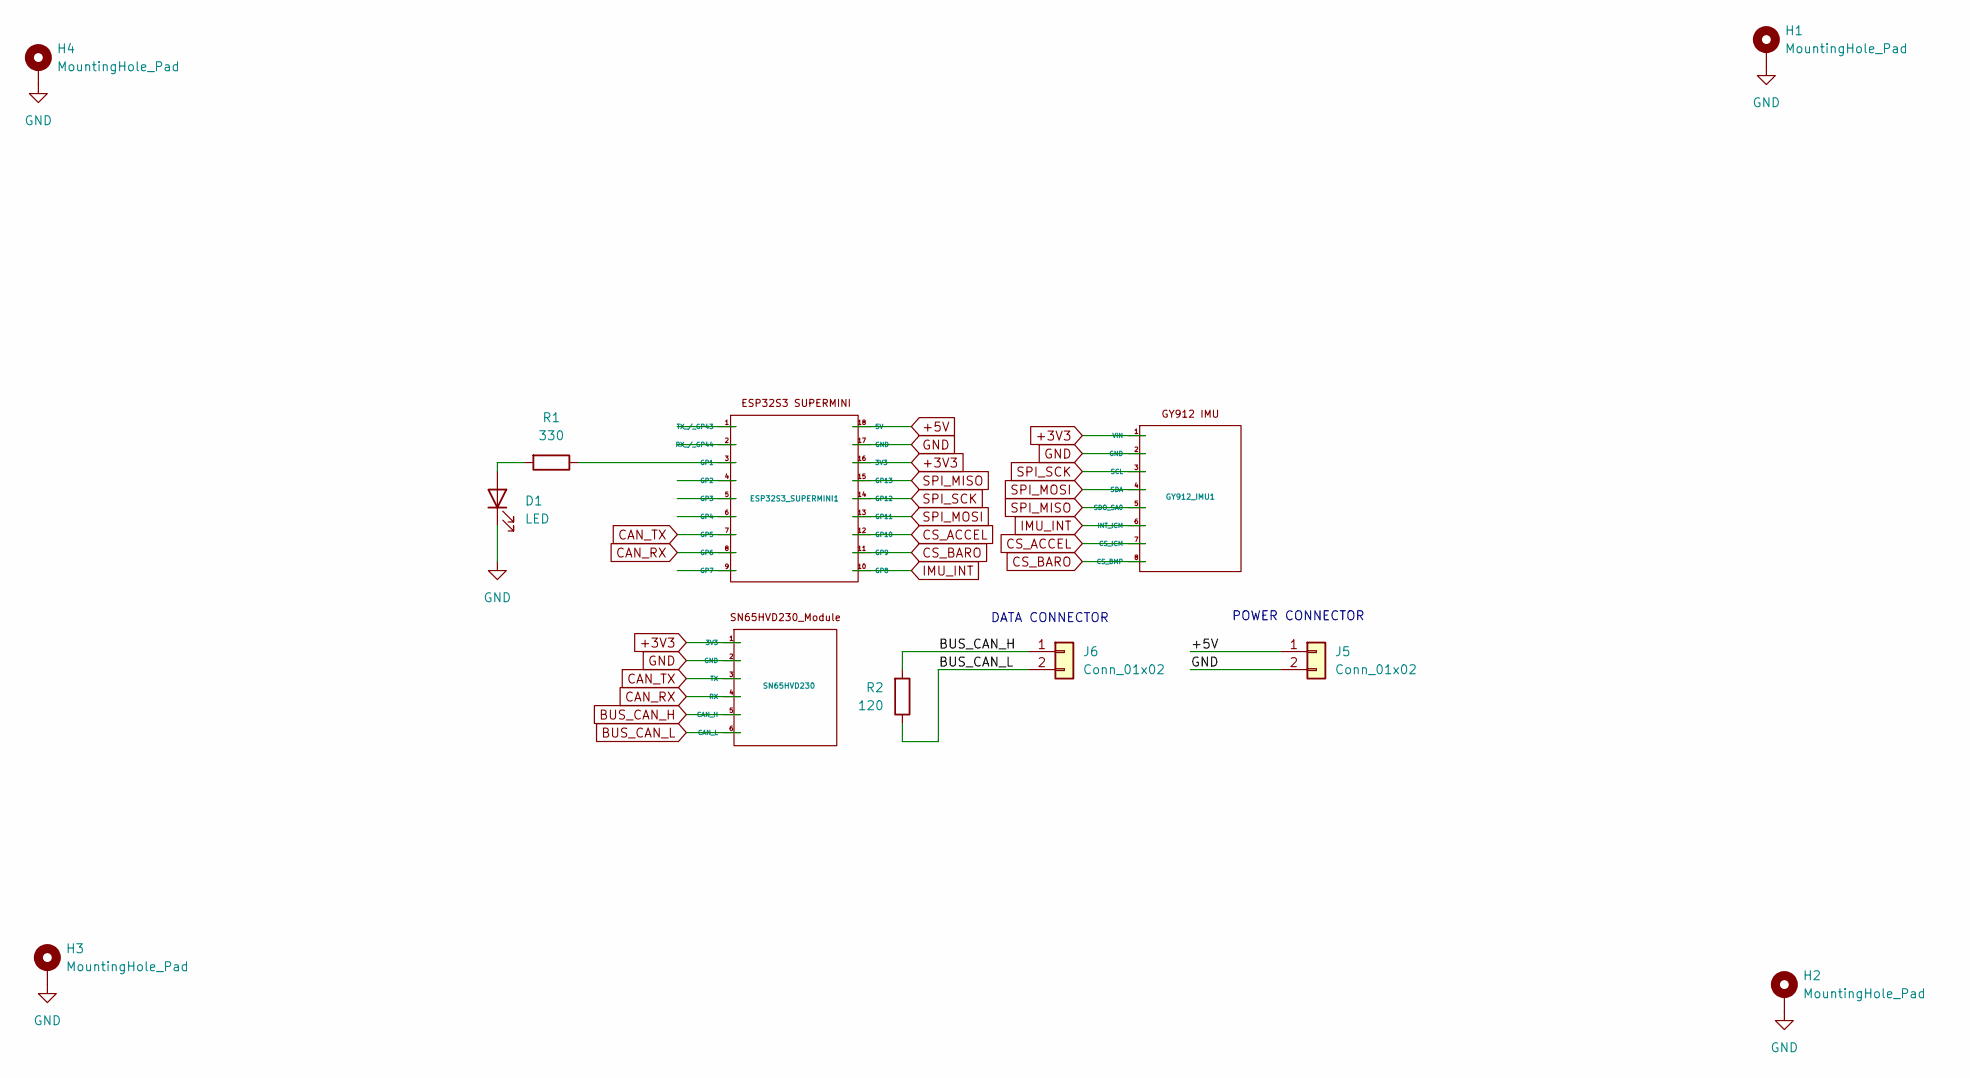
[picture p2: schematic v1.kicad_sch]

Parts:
D1: LED; LED_D3.0mm
ESP32S3_SUPERMINI1: ESP32_S3_SuperMini_Footprint
GY912_IMU1: GY-912_IMU_Footprint
H1, H2, H3, H4: MountingHole_Pad; MountingHole_3.2mm_M3_Pad_Via
J5: Conn_01x02; TerminalBlock_Phoenix_MKDS-1,5-2-5.08_1x02_P5.08mm_Horizont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
J6: Conn_01x02; JST_XH_B2B-XH-A_1x02_P2.50mm_Vertical
R1: 330; R_Axial_DIN0207_L6.3mm_D2.5mm_P7.62mm_Horizontal
R2: 120; R_Axial_DIN0207_L6.3mm_D2.5mm_P7.62mm_Horizontal
SN65HVD230: SN65HVD230_Module_Footprint

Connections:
+3V3: ESP32S3_SUPERMINI1.16 (3V3), GY912_IMU1.1 (VIN), SN65HVD230.1 (3V3)
+5V: ESP32S3_SUPERMINI1.18 (5V), J5.1
BUS_CAN_H: J6.1, R2.2, SN65HVD230.5 (CAN_H)
BUS_CAN_L: J6.2, R2.1, SN65HVD230.6 (CAN_L)
CAN_RX: ESP32S3_SUPERMINI1.8 (GP6), SN65HVD230.4 (RX)
CAN_TX: ESP32S3_SUPERMINI1.7 (GP5), SN65HVD230.3 (TX)
CS_ACCEL: ESP32S3_SUPERMINI1.12 (GP10), GY912_IMU1.7 (CS_ICM)
CS_BARO: ESP32S3_SUPERMINI1.11 (GP9), GY912_IMU1.8 (CS_BMP)
GND: D1.1 (K), ESP32S3_SUPERMINI1.17 (GND), GY912_IMU1.2 (GND), H1.1, H2.1, H3.1, H4.1, J5.2, SN65HVD230.2 (GND)
IMU_INT: ESP32S3_SUPERMINI1.10 (GP8), GY912_IMU1.6 (INT_ICM)
unnamed: D1.2 (A), R1.2
unnamed: ESP32S3_SUPERMINI1.3 (GP1), R1.1
SPI_MISO: ESP32S3_SUPERMINI1.15 (GP13), GY912_IMU1.5 (SDO_SA0)
SPI_MOSI: ESP32S3_SUPERMINI1.13 (GP11), GY912_IMU1.4 (SDA)
SPI_SCK: ESP32S3_SUPERMINI1.14 (GP12), GY912_IMU1.3 (SCL)

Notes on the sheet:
DATA CONNECTOR
POWER CONNECTOR

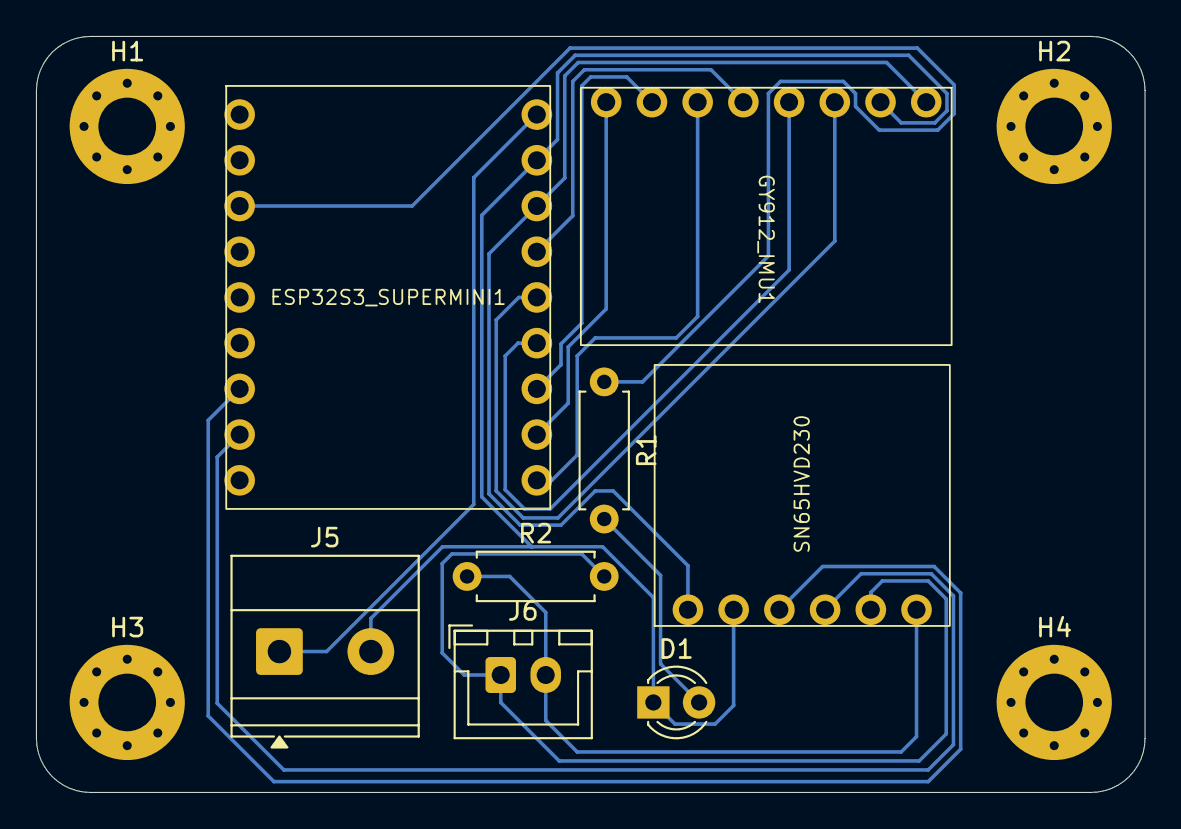
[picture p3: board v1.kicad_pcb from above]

Board: 2 copper layers, 61.6 x 42.0 mm, 12 parts (0 on the bottom side), 15 nets.

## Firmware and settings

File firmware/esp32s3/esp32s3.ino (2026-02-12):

#include "driver/twai.h"
#include "esp_task_wdt.h"
#include <Adafruit_BMP3XX.h>
#include <Adafruit_NeoPixel.h>
#include <Adafruit_Sensor.h>
#include <Arduino.h>
#include <ArduinoOTA.h> // #3: OTA
#include <ICM_20948.h>
#include <Preferences.h>
#include <SPI.h>
#include <WiFi.h>    // #3: OTA
#include <WiFiUdp.h> // UDP low-latency streaming

// --- PINS ---
#define PIN_SPI_SCK 12
#define PIN_SPI_MISO 13
#define PIN_SPI_MOSI 11
#define PIN_CS_ACCEL 10
#define PIN_CS_BARO 9
#define PIN_CAN_TX 5
#define PIN_CAN_RX 6
#define PIN_LED_EXT 1 // Rainbow LED
#define PIN_LED_OB 48 // Blinking Purple LED

// --- WATCHDOG ---
#define WDT_TIMEOUT_SEC 5

// --- #5: ALTITUDE SMOOTHING ---
#define ALT_AVG_SIZE 10

// --- #2: CAN RECEIVE COMMAND IDs ---
#define CAN_TX_ID_DEFAULT 0x101 // Outgoing: orientation data
#define CAN_RX_CMD_ID 0x200     // Incoming: commands
#define CAN_TX_HEARTBEAT 0x102  // Outgoing: heartbeat reply
// Command bytes for 0x200:
#define CMD_TARE 0x01
#define CMD_SET_SLP 0x02
#define CMD_HEARTBEAT 0x03

// --- OBJECTS & GLOBALS ---
ICM_20948_SPI myICM;
Adafruit_BMP3XX bmp;
Preferences prefs;

Adafruit_NeoPixel extLED(1, PIN_LED_EXT, NEO_GRB + NEO_KHZ800);
Adafruit_NeoPixel obLED(1, PIN_LED_OB, NEO_GRB + NEO_KHZ800);

// Shared variables (protected by mutex)
float robotYaw = 0;
float robotPitch = 0;
float robotRoll = 0;
float yawTareOffset = 0; // #2: Remote tare offset
SemaphoreHandle_t dataMutex;

// #9/#4: NVS-stored settings
float seaLevelPressure = 1013.25;
uint32_t canTxId = CAN_TX_ID_DEFAULT;
uint16_t canTxIntervalMs = 20; // 50Hz default

// Health telemetry
volatile uint32_t canTxErrors = 0;

// #1: Drift tracking
float yawDriftRate = 0;

// #5: Altitude moving average buffer
float altBuffer[ALT_AVG_SIZE];
uint8_t altBufIdx = 0;
bool altBufFull = false;

// #3: OTA state
bool otaEnabled = false;
bool otaInitialized = false;

// UDP streaming
unsigned long lastUdpSendMs = 0;
WiFiUDP udp;
const uint16_t UDP_PORT = 4210;
const IPAddress UDP_BROADCAST(192, 168, 4, 255);

// --- TASK PROTOTYPES ---
void taskSensor(void *pv);
void taskCAN(void *pv);
void taskLED(void *pv);

// --- HELPER: #5 Altitude Moving Average ---
float addAltSample(float sample) {
  altBuffer[altBufIdx] = sample;
  altBufIdx = (altBufIdx + 1) % ALT_AVG_SIZE;
  if (!altBufFull && altBufIdx == 0)
    altBufFull = true;

  uint8_t count = altBufFull ? ALT_AVG_SIZE : altBufIdx;
  if (count == 0)
    return sample;
  float sum = 0;
  for (uint8_t i = 0; i < count; i++)
    sum += altBuffer[i];
  return sum / count;
}

// --- HELPER: #3 OTA + UDP Setup ---
void setupOTA() {
  if (otaInitialized)
    return;

  WiFi.mode(WIFI_AP);
  WiFi.softAP("NAV_MODULE_OTA", "navmodule");
  Serial.print("OTA AP IP: ");
  Serial.println(WiFi.softAPIP());

  ArduinoOTA.setHostname("nav-module");
  ArduinoOTA.onStart([]() { Serial.println("OTA: Start"); });
  ArduinoOTA.onEnd([]() { Serial.println("OTA: Done, rebooting..."); });
  ArduinoOTA.onError(
      [](ota_error_t error) { Serial.printf("OTA Error [%u]\n", error); });
  ArduinoOTA.begin();

  // Start UDP for low-latency sensor streaming
  udp.begin(UDP_PORT);
  Serial.printf("UDP: Broadcasting on port %d\n", UDP_PORT);

  otaInitialized = true;
  Serial.println("OTA: Ready (connect to NAV_MODULE_OTA)");
}

void stopOTA() {
  if (!otaInitialized)
    return;
  udp.stop();
  WiFi.softAPdisconnect(true);
  WiFi.mode(WIFI_OFF);
  otaInitialized = false;
  Serial.println("OTA: Disabled");
}

// --- HELPER: #2 Save SLP to NVS ---
void saveSLP(float newSLP) {
  seaLevelPressure = newSLP;
  prefs.begin("nav", false);
  prefs.putFloat("slp", seaLevelPressure);
  prefs.end();
  Serial.print("SLP saved: ");
  Serial.println(seaLevelPressure);
}

void setup() {
  Serial.begin(115200);
  pinMode(PIN_CS_ACCEL, OUTPUT);
  digitalWrite(PIN_CS_ACCEL, HIGH);
  pinMode(PIN_CS_BARO, OUTPUT);
  digitalWrite(PIN_CS_BARO, HIGH);

  // Initialize LEDs
  extLED.begin();
  extLED.setBrightness(40);
  obLED.begin();
  obLED.setBrightness(50);

  SPI.begin(PIN_SPI_SCK, PIN_SPI_MISO, PIN_SPI_MOSI, -1);
  dataMutex = xSemaphoreCreateMutex();

  // --- 0. Load NVS Settings ---
  prefs.begin("nav", true);
  seaLevelPressure = prefs.getFloat("slp", 1013.25);
  canTxId = prefs.getUInt("canId", CAN_TX_ID_DEFAULT);
  canTxIntervalMs = prefs.getUShort("canMs", 20);
  otaEnabled = prefs.getBool("ota", false);
  prefs.end();
  Serial.printf("Config: SLP=%.2f, CAN_ID=0x%03X, CAN_ms=%d, OTA=%s\n",
                seaLevelPressure, canTxId, canTxIntervalMs,
                otaEnabled ? "ON" : "OFF");

  // --- 1. Initialize Sensor (DMP) ---
  myICM.begin(PIN_CS_ACCEL, SPI, 3000000);

  bool success = true;
  if (myICM.initializeDMP() != ICM_20948_Stat_Ok) {
    Serial.println("DMP Fail");
    obLED.setPixelColor(0, obLED.Color(255, 0, 0));
    obLED.show();
    while (1)
      ;
  }

  success &= (myICM.enableDMPSensor(INV_ICM20948_SENSOR_GAME_ROTATION_VECTOR,
                                    true) == ICM_20948_Stat_Ok);
  success &= (myICM.setDMPODRrate(DMP_ODR_Reg_Quat6, 0) == ICM_20948_Stat_Ok);
  success &= (myICM.enableFIFO() == ICM_20948_Stat_Ok);
  success &= (myICM.enableDMP() == ICM_20948_Stat_Ok);
  myICM.resetDMP();
  myICM.resetFIFO();

  // --- 2. Initialize Barometer ---
  if (!bmp.begin_SPI(PIN_CS_BARO, &SPI)) {
    Serial.println("BMP388 Fail");
  } else {
    bmp.setTemperatureOversampling(BMP3_OVERSAMPLING_8X);
    bmp.setPressureOversampling(BMP3_OVERSAMPLING_4X);
    bmp.setIIRFilterCoeff(BMP3_IIR_FILTER_COEFF_3);
    bmp.setOutputDataRate(BMP3_ODR_50_HZ);
  }

  // Initialize altitude buffer
  for (int i = 0; i < ALT_AVG_SIZE; i++)
    altBuffer[i] = 0;

  // --- 3. Initialize CAN Bus ---
  twai_general_config_t g_config = TWAI_GENERAL_CONFIG_DEFAULT(
      (gpio_num_t)PIN_CAN_TX, (gpio_num_t)PIN_CAN_RX, TWAI_MODE_NORMAL);
  twai_timing_config_t t_config = TWAI_TIMING_CONFIG_1MBITS();
  twai_filter_config_t f_config = TWAI_FILTER_CONFIG_ACCEPT_ALL();

  if (twai_driver_install(&g_config, &t_config, &f_config) == ESP_OK) {
    twai_start();
    Serial.println("CAN Active");
  }

  // --- 4. OTA (if enabled in NVS) ---
  if (otaEnabled) {
    setupOTA();
  }

  // --- 5. Start Tasks ---
  if (success) {
    xTaskCreatePinnedToCore(taskSensor, "IMU", 4096, NULL, 3, NULL, 1);
    xTaskCreatePinnedToCore(taskCAN, "CAN", 4096, NULL, 2, NULL, 0);
    xTaskCreatePinnedToCore(taskLED, "LED", 2048, NULL, 1, NULL, 0);
    Serial.println("System Active");
  }
}

void loop() {
  // Handle serial commands for OTA toggle
  if (Serial.available()) {
    String cmd = Serial.readStringUntil('\n');
    cmd.trim();
    if (cmd == "OTA_ON") {
      otaEnabled = true;
      prefs.begin("nav", false);
      prefs.putBool("ota", true);
      prefs.end();
      setupOTA();
    } else if (cmd == "OTA_OFF") {
      otaEnabled = false;
      prefs.begin("nav", false);
      prefs.putBool("ota", false);
      prefs.end();
      stopOTA();
    }
  }
  if (otaInitialized) {
    ArduinoOTA.handle();
    vTaskDelay(pdMS_TO_TICKS(50));
  } else {
    vTaskDelay(pdMS_TO_TICKS(100));
  }
}

// --- TASK 1: SENSOR DATA (Core 1, 200Hz) ---
void taskSensor(void *pv) {
  esp_task_wdt_add(NULL);

  // #1: Drift tracking variables
  float prevYaw = 0;
  unsigned long prevDriftTime = millis();
  float driftAccum = 0;
  uint16_t driftSamples = 0;

  while (1) {
    esp_task_wdt_reset();

    icm_20948_DMP_data_t data;
    myICM.readDMPdataFromFIFO(&data);

    if ((myICM.status == ICM_20948_Stat_Ok) ||
        (myICM.status == ICM_20948_Stat_FIFOMoreDataAvail)) {
      if ((data.header & DMP_header_bitmap_Quat6) > 0) {

        double q1 = ((double)data.Quat6.Data.Q1) / 1073741824.0;
        double q2 = ((double)data.Quat6.Data.Q2) / 1073741824.0;
        double q3 = ((double)data.Quat6.Data.Q3) / 1073741824.0;
        double q0 = sqrt(1.0 - ((q1 * q1) + (q2 * q2) + (q3 * q3)));

        float localRoll =
            atan2(2.0 * (q0 * q1 + q2 * q3), 1.0 - 2.0 * (q1 * q1 + q2 * q2)) *
            180.0 / PI;
        float localPitch = asin(2.0 * (q0 * q2 - q3 * q1)) * 180.0 / PI;
        float localYaw =
            atan2(2.0 * (q0 * q3 + q1 * q2), 1.0 - 2.0 * (q2 * q2 + q3 * q3)) *
            180.0 / PI;

        // #1: Calculate yaw drift rate (°/s, EMA)
        unsigned long now = millis();
        float dt = (now - prevDriftTime) / 1000.0;
        if (dt > 0.001) {
          float instantDrift = fabs(localYaw - prevYaw) / dt;
          // Handle wraparound at ±180
          if (instantDrift > 180.0 / dt)
            instantDrift = fabs(360.0 - instantDrift * dt) / dt;
          // Exponential moving average (alpha = 0.05 for smooth)
          yawDriftRate = yawDriftRate * 0.95 + instantDrift * 0.05;
          prevYaw = localYaw;
          prevDriftTime = now;
        }

        // Read barometer (outside mutex)
        float temp = 0, press = 0, rawAlt = 0, smoothAlt = 0;
        if (bmp.performReading()) {
          temp = bmp.temperature;
          press = bmp.pressure / 100.0;
          rawAlt = bmp.readAltitude(seaLevelPressure);
          smoothAlt = addAltSample(rawAlt); // #5: Moving average
        }

        // Mutex: only write shared floats
        if (xSemaphoreTake(dataMutex, portMAX_DELAY)) {
          robotYaw = localYaw;
          robotPitch = localPitch;
          robotRoll = localRoll;
          xSemaphoreGive(dataMutex);
        }

        // Send to active channel (throttled to 50Hz)
        if (otaInitialized) {
          unsigned long now_udp = millis();
          if (now_udp - lastUdpSendMs >= 20) {
            // Build CSV only when sending
            char csvLine[200];
            snprintf(
                csvLine, sizeof(csvLine),
                "0.0,0.0,0.0,%.2f,%.2f,%.2f,%.2f,0.0,0.0,0.0,%.1f,%.1f,%.1f,%"
                "lu,%lu,%.4f",
                localPitch, localRoll, localYaw, localYaw, temp, press,
                smoothAlt, (unsigned long)esp_get_free_heap_size(),
                (unsigned long)canTxErrors, yawDriftRate);
            udp.beginPacket(UDP_BROADCAST, UDP_PORT);
            udp.print(csvLine);
            udp.endPacket();
            lastUdpSendMs = now_udp;
          }
        } else if (Serial) {
          char csvLine[200];
          snprintf(
              csvLine, sizeof(csvLine),
              "0.0,0.0,0.0,%.2f,%.2f,%.2f,%.2f,0.0,0.0,0.0,%.1f,%.1f,%.1f,%"
              "lu,%lu,%.4f",
              localPitch, localRoll, localYaw, localYaw, temp, press, smoothAlt,
              (unsigned long)esp_get_free_heap_size(),
              (unsigned long)canTxErrors, yawDriftRate);
          Serial.println(csvLine);
        }
      }
    }
    vTaskDelay(pdMS_TO_TICKS(5));
  }
}

// --- TASK 2: CAN BUS (Core 0, configurable Hz) ---
void taskCAN(void *pv) {
  while (1) {
    // --- Health check & bus-off recovery ---
    twai_status_info_t status;
    if (twai_get_status_info(&status) == ESP_OK) {
      canTxErrors = status.tx_error_counter;

      if (status.state == TWAI_STATE_BUS_OFF) {
        twai_initiate_recovery();
        vTaskDelay(pdMS_TO_TICKS(100));
        twai_start();
        Serial.println("CAN: Bus-off recovery");
        vTaskDelay(pdMS_TO_TICKS(canTxIntervalMs));
        continue;
      }
    }

    // --- #2: Receive incoming commands ---
    twai_message_t rxMsg;
    while (twai_receive(&rxMsg, 0) == ESP_OK) { // Non-blocking poll
      if (rxMsg.identifier == CAN_RX_CMD_ID && rxMsg.data_length_code >= 1) {
        switch (rxMsg.data[0]) {
        case CMD_TARE: {
          // Remote tare: set current yaw as zero reference
          if (xSemaphoreTake(dataMutex, pdMS_TO_TICKS(5))) {
            yawTareOffset = robotYaw;
            xSemaphoreGive(dataMutex);
          }
          Serial.println("CAN: Remote TARE");
          break;
        }
        case CMD_SET_SLP: {
          // Set sea-level pressure: bytes[1-4] = float (little-endian)
          if (rxMsg.data_length_code >= 5) {
            float newSLP;
            memcpy(&newSLP, &rxMsg.data[1], sizeof(float));
            if (newSLP > 800.0 && newSLP < 1200.0) { // Sanity check
              saveSLP(newSLP);
            }
          }
          break;
        }
        case CMD_HEARTBEAT: {
          // Reply with heartbeat on 0x102
          twai_message_t hbReply;
          hbReply.identifier = CAN_TX_HEARTBEAT;
          hbReply.data_length_code = 2;
          hbReply.data[0] = 0xAC; // ACK
          hbReply.data[1] =
              (uint8_t)(esp_get_free_heap_size() / 1024); // Heap KB
          twai_transmit(&hbReply, pdMS_TO_TICKS(5));
          break;
        }
        }
      }
    }

    // --- Transmit orientation data ---
    twai_message_t message;
    message.identifier = canTxId; // #4: Configurable
    message.data_length_code = 6;

    if (xSemaphoreTake(dataMutex, portMAX_DELAY)) {
      int16_t y = (int16_t)(robotYaw * 100);
      int16_t p = (int16_t)(robotPitch * 100);
      int16_t r = (int16_t)(robotRoll * 100);
      xSemaphoreGive(dataMutex);

      message.data[0] = (y >> 8) & 0xFF;
      message.data[1] = y & 0xFF;
      message.data[2] = (p >> 8) & 0xFF;
      message.data[3] = p & 0xFF;
      message.data[4] = (r >> 8) & 0xFF;
      message.data[5] = r & 0xFF;

      twai_transmit(&message, pdMS_TO_TICKS(10));
    }
    vTaskDelay(pdMS_TO_TICKS(canTxIntervalMs)); // #4: Configurable
  }
}

// --- TASK 3: STATUS LED CONTROL ---
void taskLED(void *pv) {
  uint16_t blinkTimer = 0;
  bool blinkState = false;
  int16_t breathVal = 10; // Use signed to avoid underflow
  int16_t breathDir = 5;

  uint32_t purple = obLED.Color(60, 0, 150);
  uint32_t off = obLED.Color(0, 0, 0);

  while (1) {
    // External LED: OTA/WiFi status indicator
    if (otaInitialized) {
      // Pulsing blue = WiFi/OTA active
      breathVal += breathDir;
      if (breathVal >= 200) {
        breathVal = 200;
        breathDir = -5;
      }
      if (breathVal <= 10) {
        breathVal = 10;
        breathDir = 5;
      }
      extLED.setPixelColor(0, extLED.Color(0, 0, (uint8_t)breathVal));
    } else {
      // Solid green = normal operation
      extLED.setPixelColor(0, extLED.Color(0, 80, 0));
    }
    extLED.show();

    // Onboard LED: heartbeat blink (purple)
    blinkTimer++;
    if (blinkTimer >= 15) {
      blinkState = !blinkState;
      obLED.setPixelColor(0, blinkState ? purple : off);
      obLED.show();
      blinkTimer = 0;
    }

    vTaskDelay(pdMS_TO_TICKS(100)); // 10Hz is fine for status LEDs
  }
}

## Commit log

2026-02-10 Add PCB design documentation with block diagram and BOM
2026-02-11 v5.1: DMP sensor fusion, 3-task FreeRTOS, cyberpunk dashboard, updated docs
2026-02-11 v5.3: drift indicator, bidirectional CAN, OTA, NVS config, altitude smoothing, compass rose, theme toggle, error counters, unit tests
    [esp32s3.ino]
2026-02-12 Update to v5.4: UDP Streaming & Power Optimization
